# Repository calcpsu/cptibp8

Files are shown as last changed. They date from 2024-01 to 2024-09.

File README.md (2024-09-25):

# CalcPack TI BP8

A Li-Po battery replacement design for TI BP7/8/9 battery pack calculators - e.g. TI-55, TI-30, TI Programmer, etc. The original batteries had ~ 500mAh capacity (@2.4V: 1.2Wh), while a typical 9V alkaline battery substitution as ~500mAh (@9V: 4.5Wh), albeit single-use only.

Li-Po has the advantage of far reduced self-discharge in comparison to Ni-Cd, which is an advantage for an intermittently-used device. Even with similar mAh capacity, we can expect longer battery life.

Ni-CD batteries are notorious for leaking. While Lithium Ion batteries are notorious for self-immolation, a well protected Li-Po battery (particularly in a low current application like this) should be able to be made very safe.

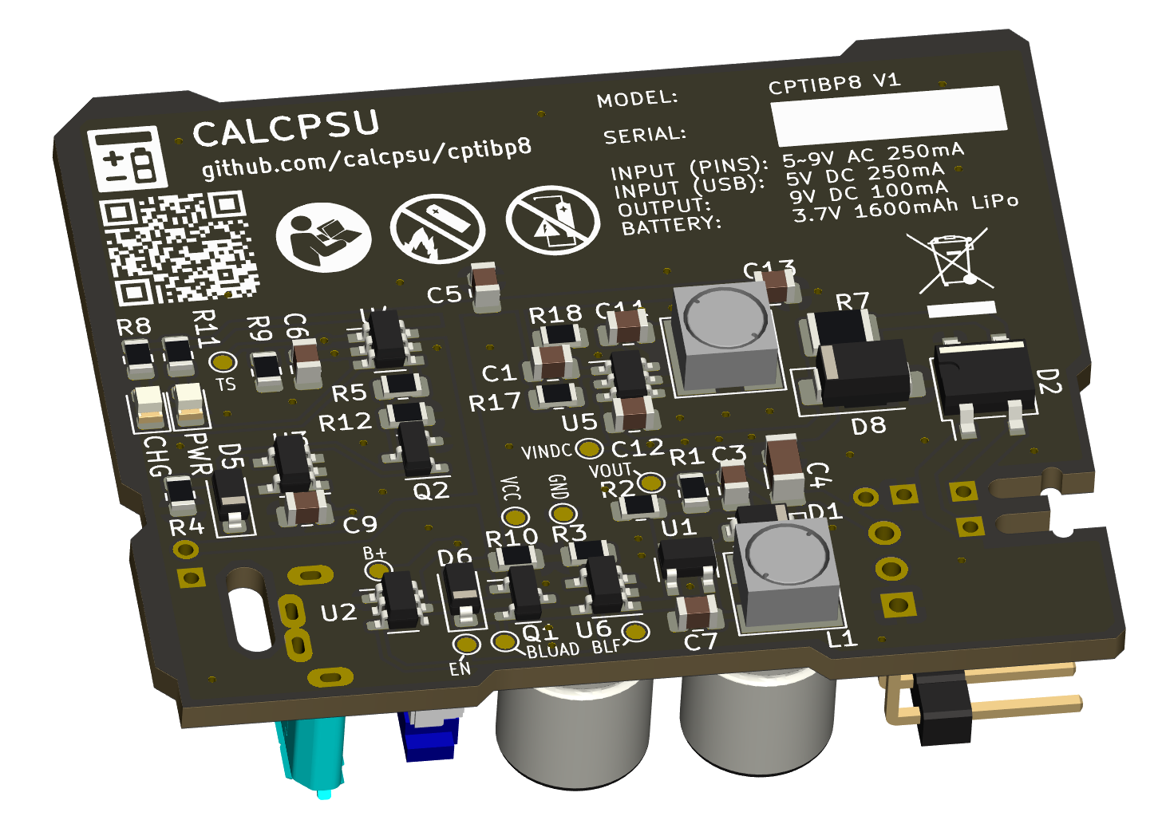
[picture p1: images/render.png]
Render of calcpack PCB


## Features / design goals:
- Direct replacement for a BP8 battery pack, compatible with TI55, TI30, TI Programmer (and other Majestic series).
    - Support both 9V battery snap terminal and 3-pin molex connector output
- Compatible with existing charging connection (2-pin AC input; somewhere from 5 to 9VAC)
    - Provides adequate smoothing of rectified AC
    - Provides voltage clamping / overvoltage protection
- Efficient conversion of input rectified supply to 5VDC for charging IC and calculator operation
- Step up from battery or input rectified supply to 9VDC for calculator supply
- Protected from:
    - Overvoltage (input) at 2x rated voltage and current (IATA requirement)
    - Overcharging (4.2V)
    - Over-discharge (3.1V shutdown, 2.5V cutoff in battery pack)
    - Short circuit and overcurrent (again for IATA requirement)
- Minimum idle/quiescent current to maximise charge time
- Similar or higher capacity than typical Ni-MH altenative (1500mAh @ 2.4V: 3.6Wh)

## Case ##

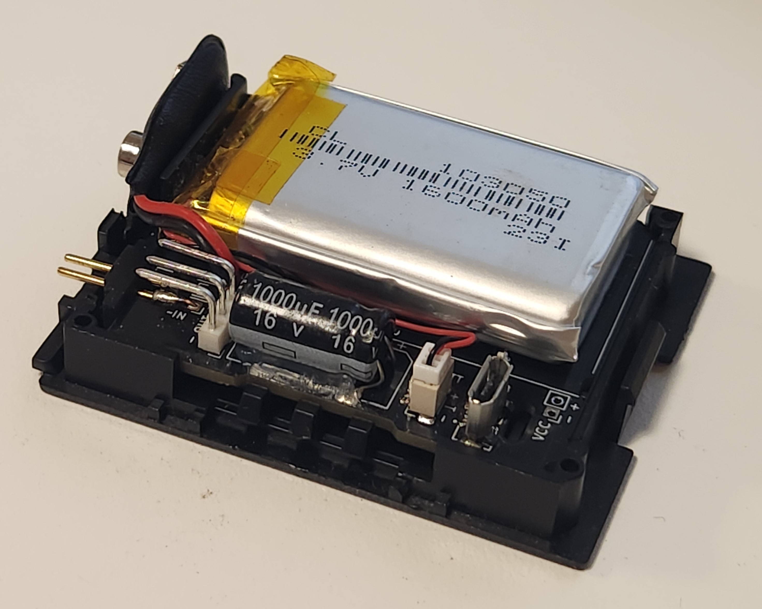
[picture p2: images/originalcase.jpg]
Photo of calcpack in original case


The board is designed to fit into the original TI case bottom part, to preserve an original look!

1. The simplest installation is to place the board and 3D printed standoff into the original case bottom, with a dab of hot glue to hold it in place.
    * The original back cover will not fit, due to ridges for cylindrical cells - you can leave it off.
    * If you prefer, a 3d-printed replacement top cover is provided compatible with the original bottom part. Due to tolerances and thin snaps, SLA 3D printing is recommended (and use a semi-flexible material, such as ABS-like resin).
3. If you don't have an original case, a case designed specifically for 3D printing is available (image below).
    * Files with and without support (intended for SLA printing) are provided.
    * The top part is not required. It is designed to be attached with a couple of dots of superglue.

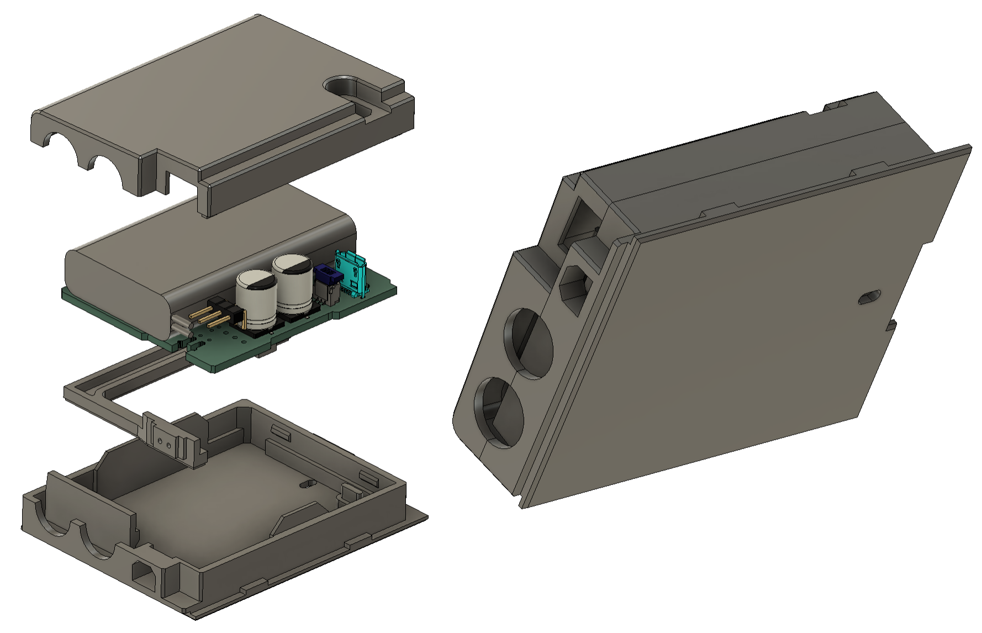
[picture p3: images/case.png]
Render of 3d printable calcpack case


## Availability ##

If you'd like one of these, I may be able to help! Please contact me at info@calcpsu.com.au.
  
## License

This work is licensed under a
[Creative Commons Attribution-NonCommercial-ShareAlike 4.0 International License][cc-by-nc-sa].

[][cc-by-nc-sa]

[cc-by-nc-sa]: http://creativecommons.org/licenses/by-nc-sa/4.0/
[cc-by-nc-sa-image]: https://licensebuttons.net/l/by-nc-sa/4.0/88x31.png
[cc-by-nc-sa-shield]: https://img.shields.io/badge/License-CC%20BY--NC--SA%204.0-lightgrey.svg

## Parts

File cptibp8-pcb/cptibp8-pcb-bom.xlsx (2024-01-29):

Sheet: cptibp8-pcb
Id | Designator | Footprint | Quantity | Designation | Supplier and ref | Column1 | _1 | MPN
6 | BT1 | JST_SH_BM03B-SRSS-TB_1x03-1MP_P1.00mm_Vertical | 1 | LiPo |  |  |  | BM03B-SRSS-TB
25 | C1 | C_0805_2012Metric | 1 | 100p |  |  |  | CC0805KRX7R8BB101
12 | C11 | C_0805_2012Metric | 1 | 22n |  |  |  | CC0805KRX7R8BB223
14 | C13,C12,C2 | C_0805_2012Metric | 3 | 1u |  |  |  | CL21B105KAFNNNE
18 | C3 | C_0805_2012Metric | 1 | 1n |  |  |  | CL21C472JAFNNNE
43 | C4 | C_1206_3216Metric | 1 | 22u |  |  |  | CL31A226KAHNNNE
41 | C5 | C_0805_2012Metric | 1 | 10u |  |  |  | CL21A106KAYNNNE
46 | C7,C6 | C_0805_2012Metric | 2 | 4u7 |  |  |  | CL21A475KAQNNNE
3 | C8,C10 | CP_Elec_8x10.5 | 2 | 470u/25V |  |  |  | EEE-FP1C471AP
34 | D1,D6 | D_SOD-123 | 2 | PMEG40T10ERX |  |  |  | PMEG40T10ERX
17 | D2 | TO-269AA | 1 | MB14S |  |  |  | MB14S
28 | D3 | LED_0805_2012Metric | 1 | RED |  |  |  | B1701USD-20D000114U1930
35 | D4 | LED_0805_2012Metric | 1 | GRN |  |  |  | B1701UYG-20D000114U1930
36 | D8 | D_SMA | 1 | Z15V |  |  |  | 3SMAJ5929B-TP
45 | F1 | Fuse_1210_3225Metric | 1 | 0ZCJ0035AF2E |  |  |  | 0ZCJ0035AF2E
1 | J1 | PinHeader_1x01_P2.00mm_Vertical | 1 | VAC2 |  |  |  | #N/A
2 | J2 | PinHeader_1x02_P2.00mm_Vertical | 1 | OUT |  |  |  | 232
7 | J3 | PinHeader_1x02_P2.00mm_Vertical | 1 | VCC |  |  |  | #N/A
4 | J4 | PinHeader_1x03_P2.54mm_Vertical | 1 | OUT |  |  |  | 22052031
5 | J5 | PinHeader_1x01_P2.00mm_Vertical | 1 | VAC1 |  |  |  | #N/A
31 | L2,L1 | Inductor_Bourns_SRR4028 | 2 | 10uH |  |  |  | SRR4028-100Y
24 | Q1 | SOT-23 | 1 | AO3413 |  |  |  | AO3413
19 | Q3 | SOT-23 | 1 | DMG2302UK |  |  |  | DMG2302U-7
23 | R1 | R_0805_2012Metric | 1 | 576k |  |  |  | RC0805FR-07576KL
10 | R10 | R_0805_2012Metric | 1 | 47k |  |  |  | RC0805FR-0747KL
11 | R11,R8 | R_0805_2012Metric | 2 | 3k |  |  |  | RC0805FR-073KL
29 | R14 | R_0805_2012Metric | 1 | 5k4 |  |  |  | RC0805FR-071K3L
16 | R17 | R_0805_2012Metric | 1 | 49.9k |  |  |  | RC0805FR-0749K9L
42 | R18 | R_0805_2012Metric | 1 | 9.1k |  |  |  | RC0805FR-079K1L
44 | R2 | R_0805_2012Metric | 1 | 91k |  |  |  | RC0805FR-0791KL
21 | R6 | R_0805_2012Metric | 1 | 1M |  |  |  | RC0805FR-7W1ML
30 | R7 | R_1210_3225Metric | 1 | 1 |  |  |  | RC1210FR-071RL
15 | R9 | R_0805_2012Metric | 1 | 10k |  |  |  | RC0805FR-0710KL
22 | TP1 | TestPoint_Pad_D1.0mm | 1 | VINDC |  |  |  | #N/A
26 | TP10 | TestPoint_Pad_D1.0mm | 1 | VOUTN |  |  |  | #N/A
13 | TP2 | TestPoint_Pad_D1.0mm | 1 | B+ |  |  |  | #N/A
33 | TP3 | TestPoint_Pad_D1.0mm | 1 | BLOAD |  |  |  | #N/A
40 | TP4 | TestPoint_Pad_D1.0mm | 1 | VOUT |  |  |  | #N/A
48 | TP5 | TestPoint_Pad_D1.0mm | 1 | VOUTF |  |  |  | #N/A
38 | TP6 | TestPoint_Pad_D1.0mm | 1 | GND |  |  |  | #N/A
47 | TP7 | TestPoint_Pad_D1.0mm | 1 | EN |  |  |  | #N/A
20 | TP8 | TestPoint_Pad_D1.0mm | 1 | TS |  |  |  | #N/A
39 | TP9 | TestPoint_Pad_D1.0mm | 1 | VCC |  |  |  | #N/A
37 | U1 | SOT-23-5_TI_DBV5 | 1 | MIC2250-1YD5-TR |  |  |  | MIC2250-1YD5-TR
9 | U2 | SOT-23-3 | 1 | APX803S-31SA |  |  |  | APX803S-31SA
32 | U4 | SOT-23-6_TI_DBV6 | 1 | BQ21040 |  |  |  | BQ21040DBVR
27 | U5 | TSOT-23-6 | 1 | AP63200WU |  |  |  | AP63200WU-7

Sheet: Sheet1
LiPo | BM03B-SRSS-TB
100p | CC0805KRX7R8BB101
22n | CC0805KRX7R8BB223
1u | CL21B105KAFNNNE
1n | CL21C472JAFNNNE
22u | CL31A226KAHNNNE
10u | CL21A106KAYNNNE
4u7 | CL21A475KAQNNNE
470u/25V | EEE-FP1C471AP
PMEG40T10ERX | PMEG40T10ERX
MB14S | MB14S
RED | B1701USD-20D000114U1930
GRN | B1701UYG-20D000114U1930
Z15V | 3SMAJ5929B-TP
0ZCJ0035AF2E | 0ZCJ0035AF2E
VAC2 | #N/A
OUT | 232
VCC | #N/A
OUT | 22052031
VAC1 | #N/A
10uH | SRR4028-100Y
AO3413 | AO3413
DMG2302UK | DMG2302U-7
576k | RC0805FR-07576KL
47k | RC0805FR-0747KL
3k | RC0805FR-073KL
5k4 | RC0805FR-071K3L
49.9k | RC0805FR-0749K9L
9.1k | RC0805FR-079K1L
91k | RC0805FR-0791KL
1M | RC0805FR-7W1ML
1 | RC1210FR-071RL
10k | RC0805FR-0710KL
VINDC | #N/A
VOUTN | #N/A
B+ | #N/A
BLOAD | #N/A
VOUT | #N/A
VOUTF | #N/A
GND | #N/A
EN | #N/A
TS | #N/A
VCC | #N/A
MIC2250-1YD5-TR | MIC2250-1YD5-TR
APX803S-31SA | APX803S-31SA
BQ21040 | BQ21040DBVR
AP63200WU | AP63200WU-7

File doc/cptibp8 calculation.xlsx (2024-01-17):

Parameter | Value | Unit
Calculator current | 60 | mA
U1 output voltage | 8.9 | V
U1 output power | 534 | mW
U1 efficiency | 85% | W/W
U1 input power | 628.2352941 | mW
VCC diode drop | 0.4 | V
VCC | 5.2 | V
BLOAD voltage | 4.8 | V
U1 input current | 130.8823529 | mA
VCC diode power | 52.35294118 | mW
Charge current | 100 | mA
U6 output power | 1200.588235 | mW
U6 efficiency | 90%
U6 input power | 1333.986928 | mW
Input voltage | 5.7 | VAC
Input current | 234.0327944 | mVAC

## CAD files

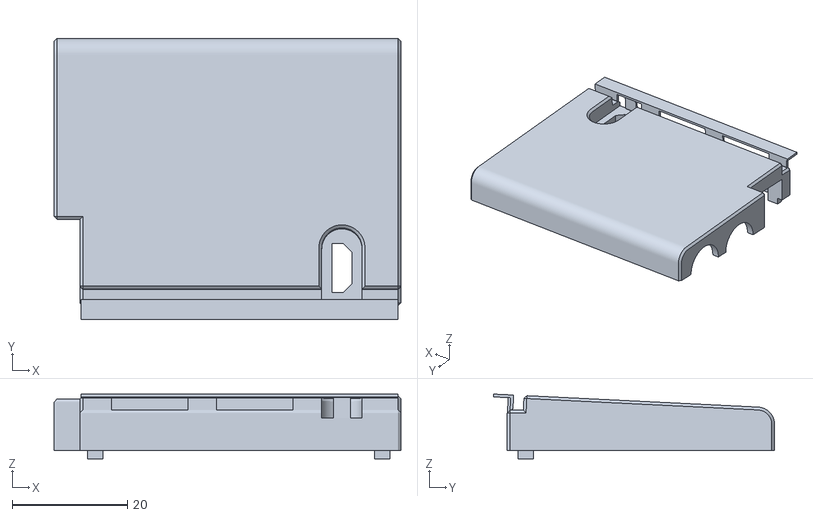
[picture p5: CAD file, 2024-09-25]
case/cptibp8_case_new_top_SLASUPPORT.stl
60.2 x 48.8 x 11.3

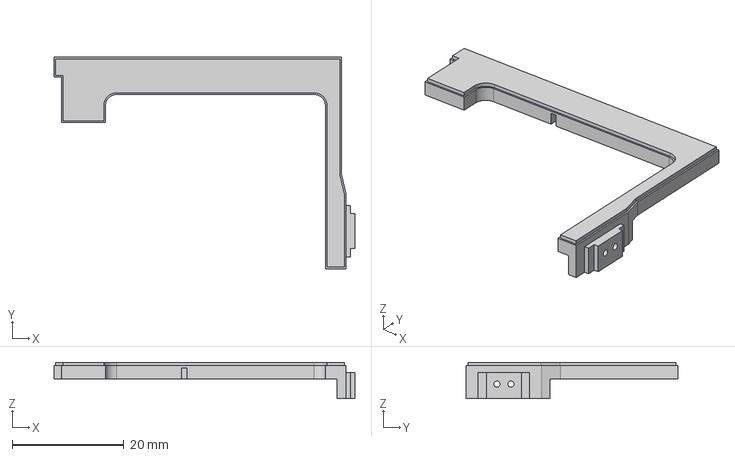
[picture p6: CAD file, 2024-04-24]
cptibp8-enclosure-spacer.step
53.8 x 37.8 x 6.50 mm

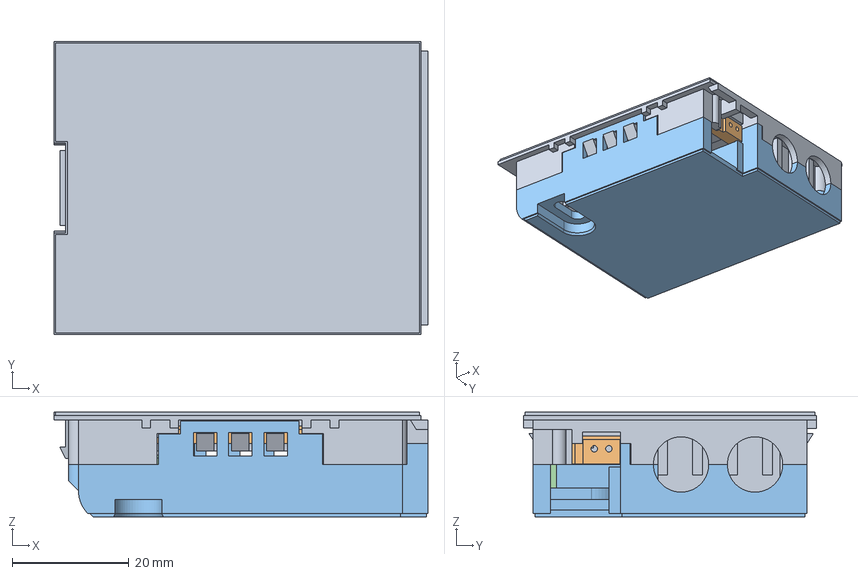
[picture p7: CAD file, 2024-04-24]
cptibp8-pcb/cptibp8-enclosure.step
64.2 x 50.3 x 18.0 mm

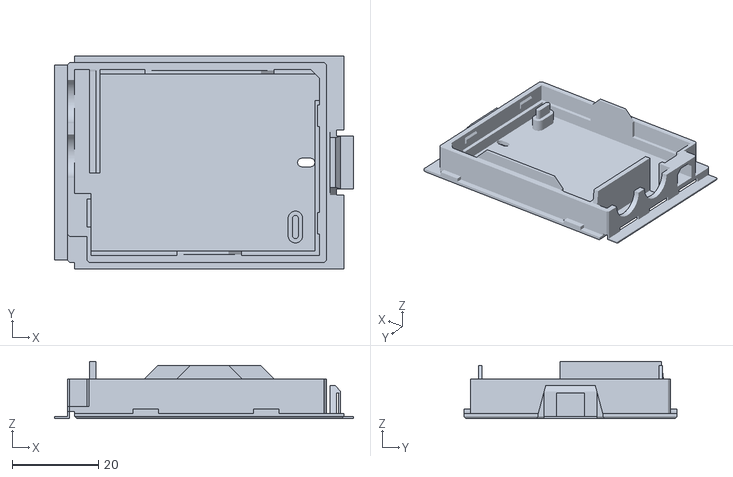
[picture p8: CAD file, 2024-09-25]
case/cptibp8_case_new_bottom_SLASUPPORT.stl
69.5 x 49.6 x 13.3

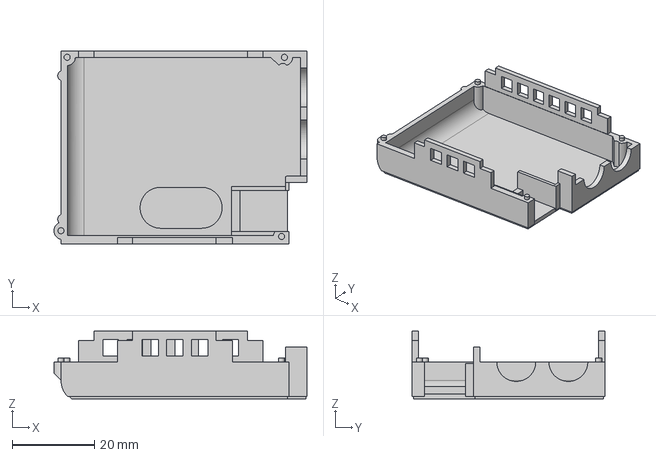
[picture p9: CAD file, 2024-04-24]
cptibp8-enclosure-lid.step
61.7 x 47.0 x 16.5 mm

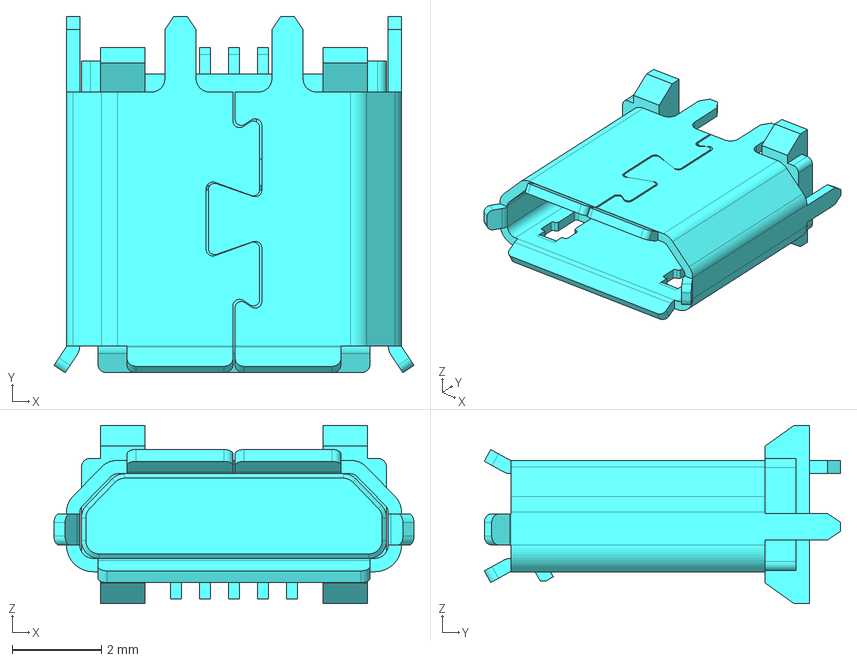
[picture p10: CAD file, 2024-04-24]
cptibp8-pcb/3d/ZX80-B-5P_30__1.step
8.08 x 8.00 x 4.00 mm

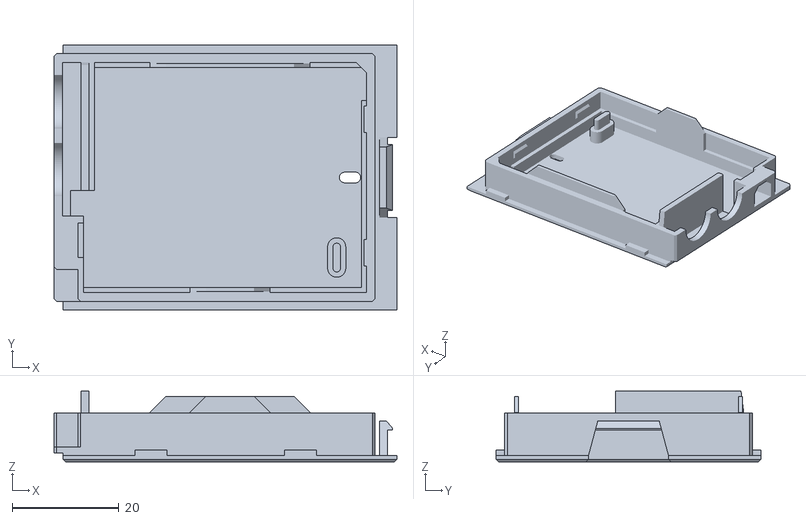
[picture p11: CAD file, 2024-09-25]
case/cptibp8_case_new_bottom.stl
64.3 x 49.6 x 13.3

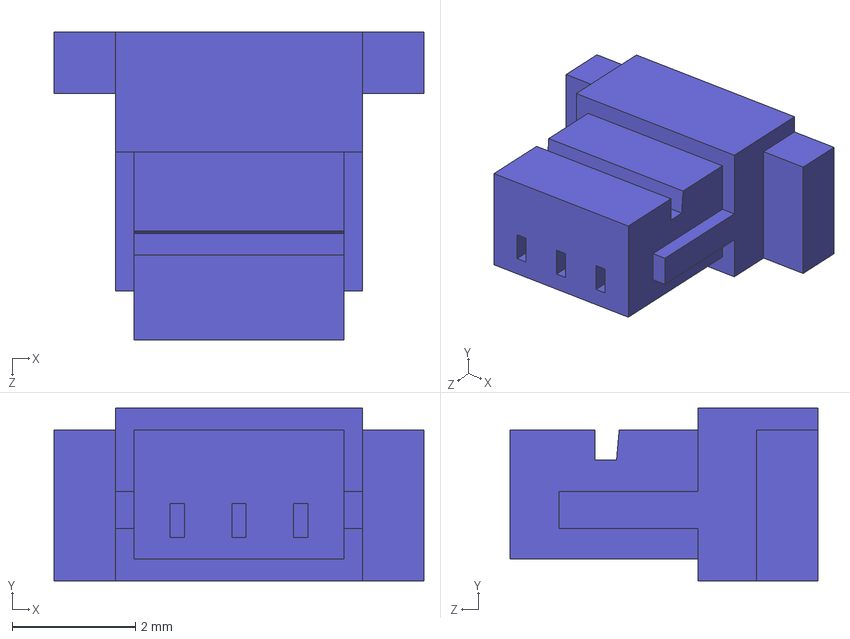
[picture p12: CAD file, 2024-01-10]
cptibp8-pcb/3d/SHR-03V-S-B.STEP
6.00 x 2.80 x 5.00 mm

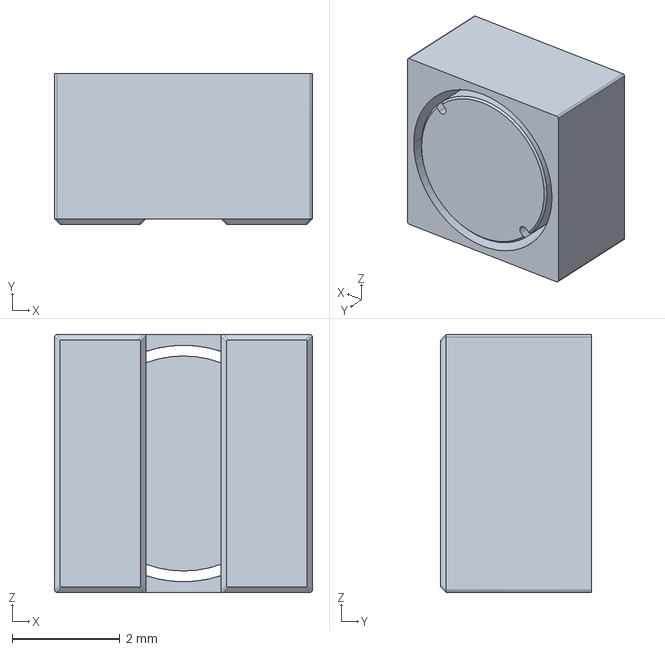
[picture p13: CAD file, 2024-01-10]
cptibp8-pcb/3d/srr4028.stp
4.80 x 2.80 x 4.80 mm

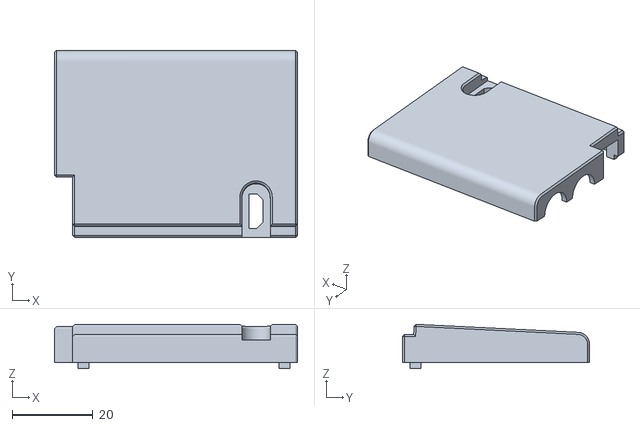
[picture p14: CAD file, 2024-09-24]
case/cptibp8_case_new_top.stl
60.2 x 46.4 x 11.0

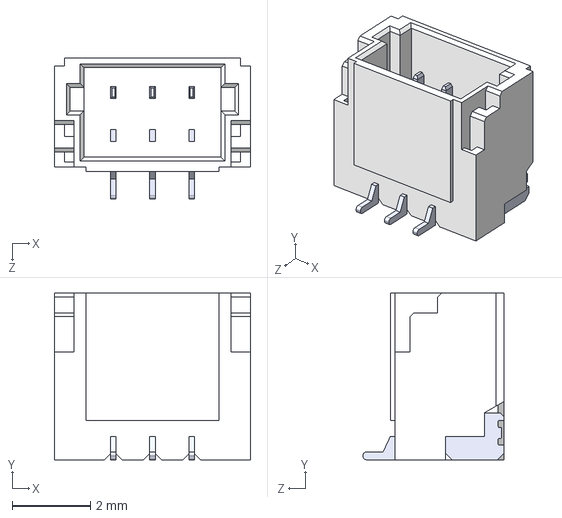
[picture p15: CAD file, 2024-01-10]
cptibp8-pcb/3d/BM03B-SRSS-TB.STEP
5.00 x 4.25 x 3.60 mm

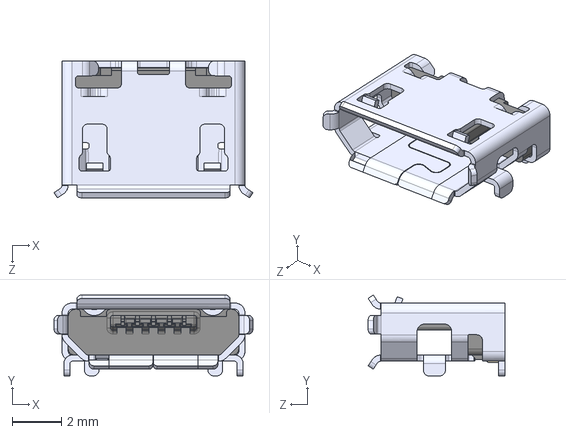
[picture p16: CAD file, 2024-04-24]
cptibp8-pcb/3d/10118194-0001LF.step
8.05 x 3.27 x 5.53 mm

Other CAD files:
case/cptibp8_case_original_top.stl
case/cptibp8_case_new_standoff.stl

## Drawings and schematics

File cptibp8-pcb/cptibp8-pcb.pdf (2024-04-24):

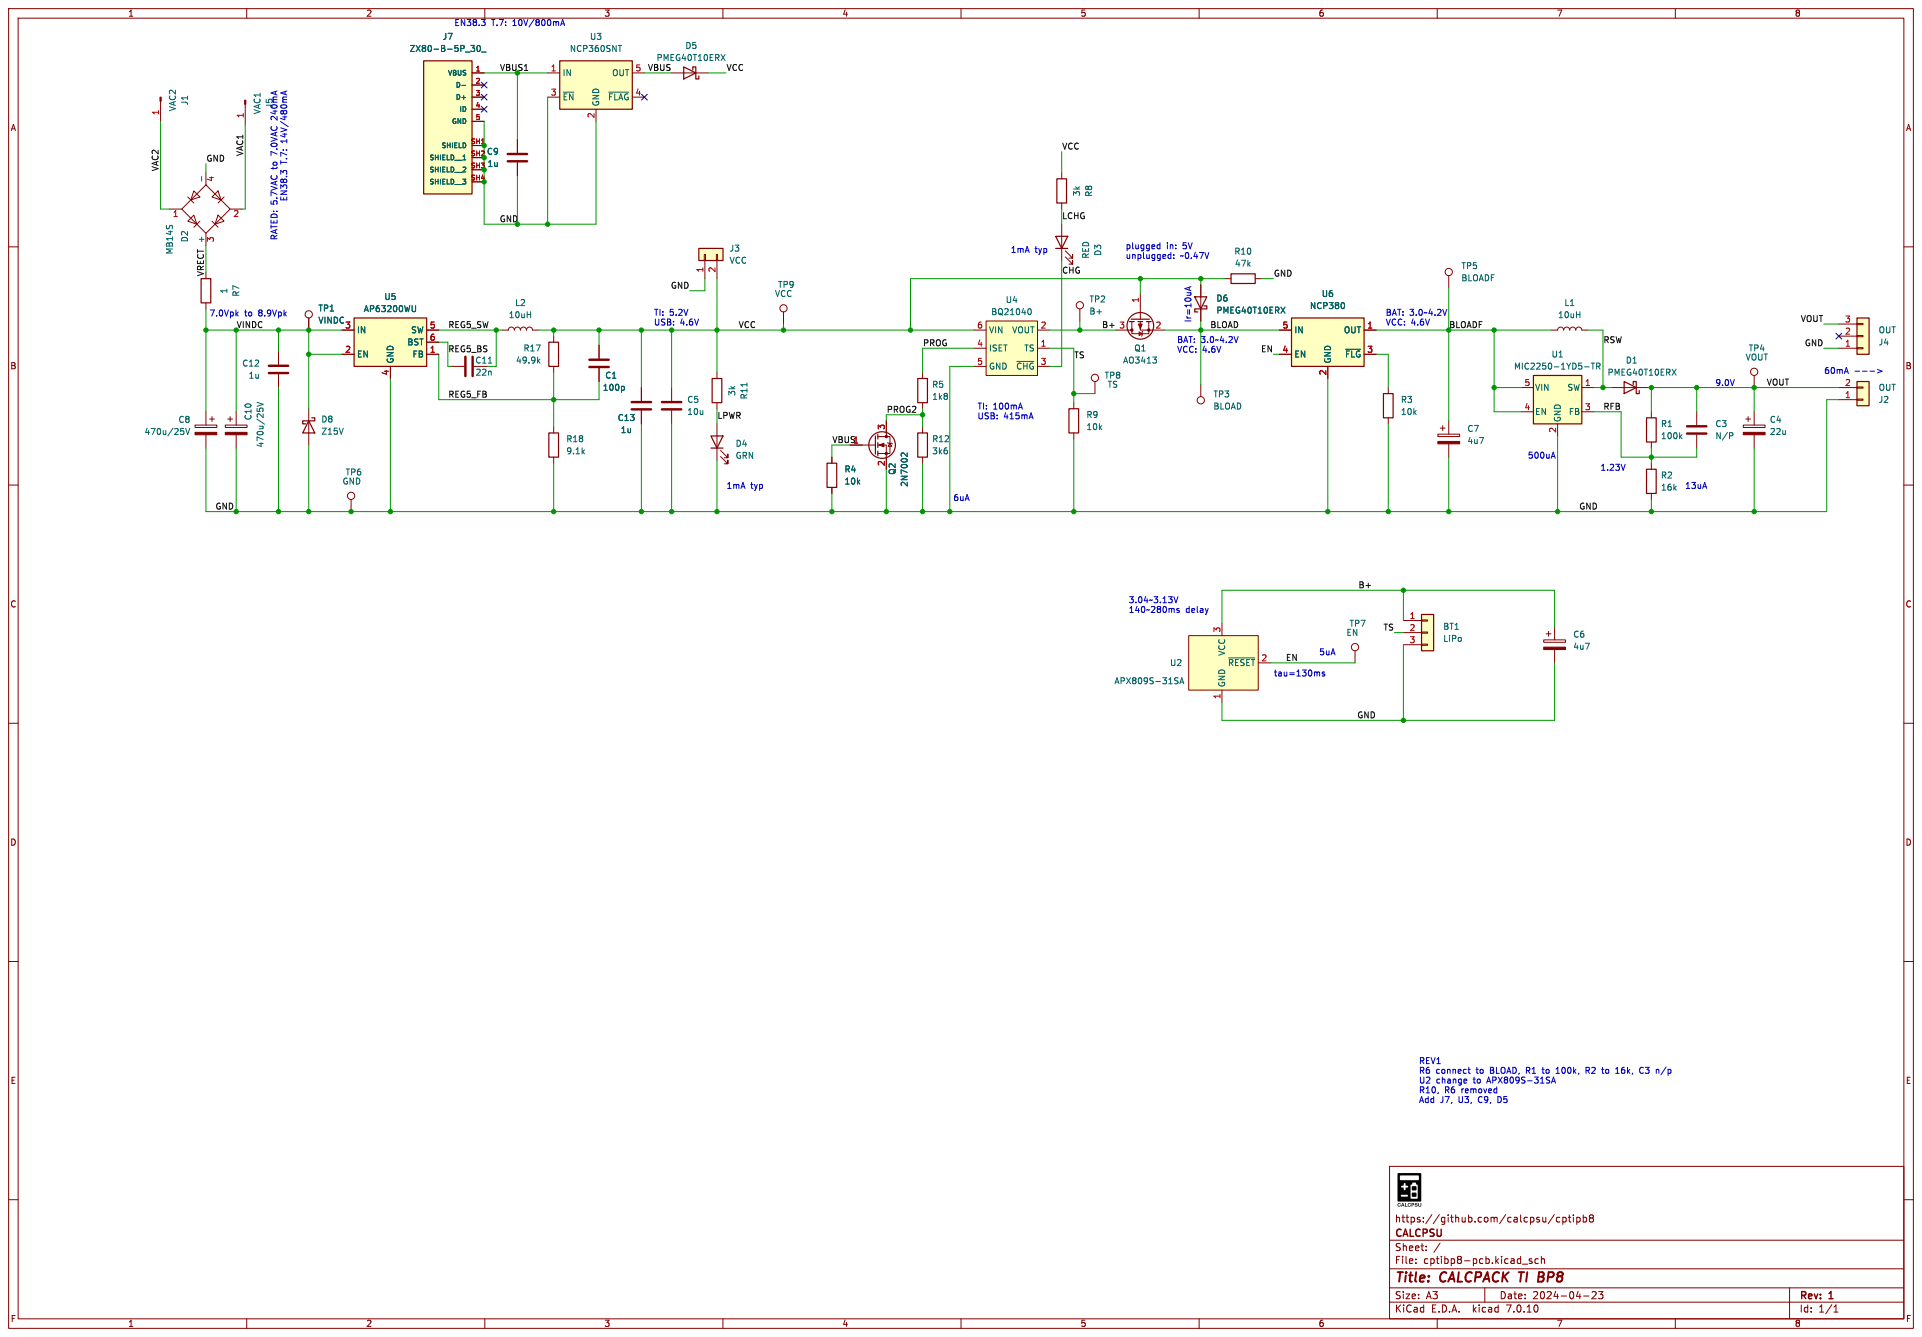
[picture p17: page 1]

2 FB 3 EN 4 VIN 5 U1 MIC2250-1YD5-TR

REV1 R6 connect to BLOAD, R1 to 100k, R2 to 16k, C3 n/p U2 change to APX809S-31SA R10, R6 removed Add J7, U3, C9, D5

https://github.com/calcpsu/cptipb8
File: cptibp8-pcb.kicad_sch Sheet: / CALCPSU

Id: 1/1 Title: CALCPACK TI BP8

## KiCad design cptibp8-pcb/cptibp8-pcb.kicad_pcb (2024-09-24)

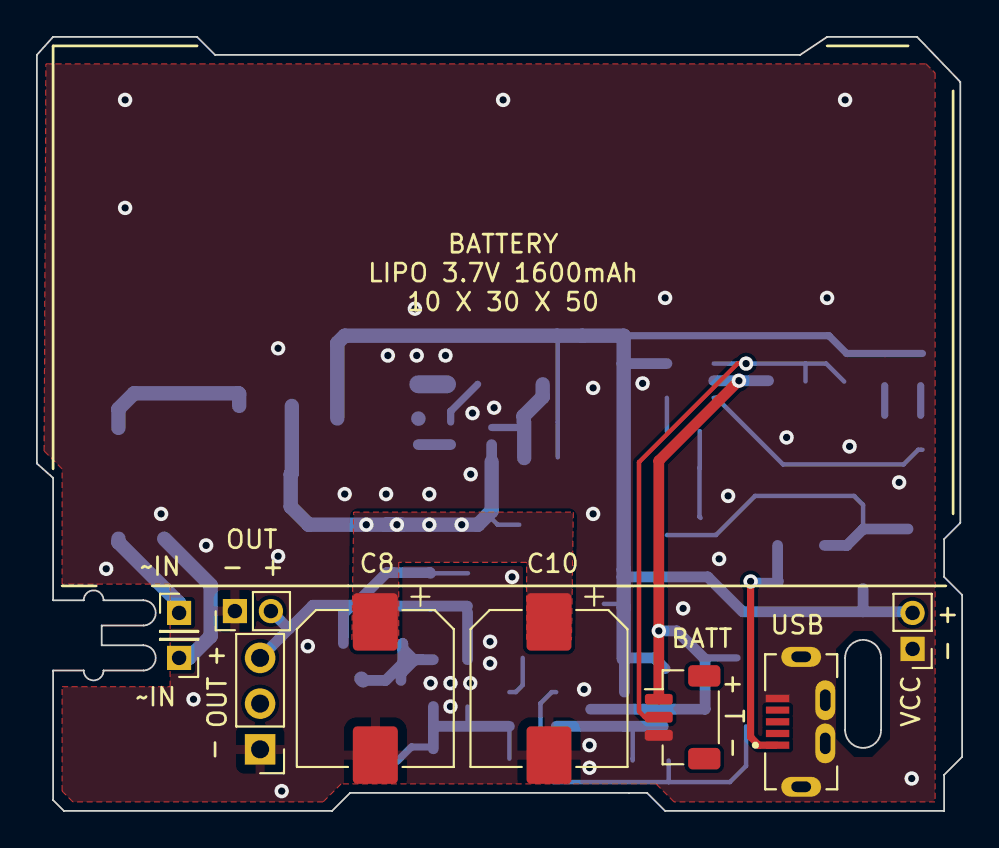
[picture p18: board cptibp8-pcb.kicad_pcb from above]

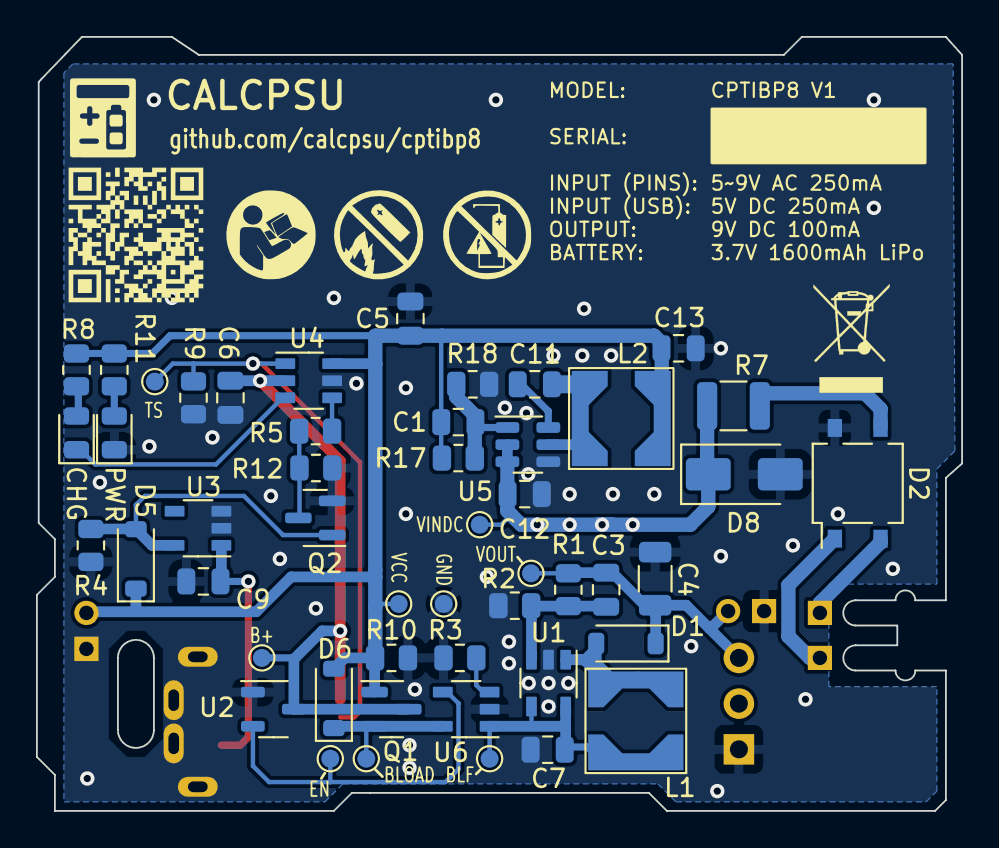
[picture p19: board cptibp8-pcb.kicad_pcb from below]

Board: 2 copper layers, 51.4 x 43.0 mm, 58 parts (49 on the bottom side), 25 nets.

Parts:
BT1: LiPo; JST_SH_BM03B-SRSS-TB_1x03-1MP_P1.00mm_Vertical
C1: 100p; C_0805_2012Metric
C3: N/P; C_0805_2012Metric
C4: 22u; C_1206_3216Metric
C5: 10u; C_0805_2012Metric
C6, C7: 4u7; C_0805_2012Metric
C8, C10: 470u/25V; CP_Elec_8x10.5
C9, C12, C13: 1u; C_0805_2012Metric
C11: 22n; C_0805_2012Metric
D1, D5, D6: PMEG40T10ERX; D_SOD-123
D2: MB14S; TO-269AA
D3: RED; LED_0805_2012Metric
D4: GRN; LED_0805_2012Metric
D8: Z15V; D_SMA
J1: VAC2; PinHeader_1x01_P2.00mm_Vertical
J2: OUT; PinHeader_1x02_P2.00mm_Vertical
J3: VCC; PinHeader_1x02_P2.00mm_Vertical
J4: OUT; PinHeader_1x03_P2.54mm_Vertical
J5: VAC1; PinHeader_1x01_P2.00mm_Vertical
J7: ZX80-B-5P_30_; HRS_ZX80-B-5P_30_
L1, L2: 10uH; Inductor_Bourns_SRR4028
Q1: AO3413; SOT-23
Q2: 2N7002; SOT-23
R1: 100k; R_0805_2012Metric
R2: 16k; R_0805_2012Metric
R3, R4, R9: 10k; R_0805_2012Metric
R5: 1k8; R_0805_2012Metric
R7: 1; R_1210_3225Metric
R8, R11: 3k; R_0805_2012Metric
R10: 47k; R_0805_2012Metric
R12: 3k6; R_0805_2012Metric
R17: 49.9k; R_0805_2012Metric
R18: 9.1k; R_0805_2012Metric
TP1: VINDC; TestPoint_Pad_D1.0mm
TP2: B+; TestPoint_Pad_D1.0mm
TP3: BLOAD; TestPoint_Pad_D1.0mm
TP4: VOUT; TestPoint_Pad_D1.0mm
TP5: BLOADF; TestPoint_Pad_D1.0mm
TP6: GND; TestPoint_Pad_D1.0mm
TP7: EN; TestPoint_Pad_D1.0mm
TP8: TS; TestPoint_Pad_D1.0mm
TP9: VCC; TestPoint_Pad_D1.0mm
U1: MIC2250-1YD5-TR; SOT-23-5_TI_DBV5
U2: APX809S-31SA; SOT-23-3
U3: NCP360SNT; SOT-23-5_TI_DBV5
U4: BQ21040; SOT-23-6_TI_DBV6
U5: AP63200WU; TSOT-23-6
U6: NCP380; SOT-23-5_TI_DBV5

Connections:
/B+: BT1.1, C6.1, Q1.3 (D), TP2.1, U2.3 (VCC), U4.2 (VOUT)
/BLOAD: D6.1 (K), Q1.2 (S), TP3.1, U6.5 (IN)
/BLOADF: C7.1, L1.1, TP5.1, U1.4 (EN), U1.5 (VIN), U6.1 (OUT)
/CHG: D3.1 (K), U4.3 (~CHG)
/EN: TP7.1, U2.2 (~RESET), U6.4 (EN)
/GND: BT1.3, C4.2, C5.2, C6.2, C7.2, C8.2, C9.2, C10.2, C12.2, C13.2, D2.4 (-), D4.1 (K), D8.2 (A), J2.1, J3.1, J4.1, J7.5 (GND), J7.SH1 (SHIELD), J7.SH2 (SHIELD__1), J7.SH3 (SHIELD__2), J7.SH4 (SHIELD__3), Q2.2 (S), R2.1, R3.1, R4.1, R9.1, R10.1, R12.1, R18.2, TP6.1, U1.2 (GND), U2.1 (GND), U3.2 (GND), U3.3 (~EN), U4.5 (GND), U5.4 (GND), U6.2 (GND)
/LCHG: D3.2 (A), R8.1
/LPWR: D4.2 (A), R11.1
/PROG: R5.2, U4.4 (ISET)
/PROG2: Q2.3 (D), R5.1, R12.2
/REG5_BS: C11.1, U5.6 (BST)
/REG5_FB: C1.1, R17.2, R18.1, U5.1 (FB)
/REG5_SW: C11.2, L2.1, U5.5 (SW)
/RFB: C3.1, R1.2, R2.2, U1.3 (FB)
/RSW: D1.2 (A), L1.2, U1.1 (SW)
/TS: BT1.2, R9.2, TP8.1, U4.1 (TS)
/VAC1: D2.2, J5.1
/VAC2: D2.1, J1.1
/VBUS: D5.2 (A), Q2.1 (G), R4.2, U3.5 (OUT)
/VBUS1: C9.1, J7.1 (VBUS), U3.1 (IN)
/VCC: C1.2, C5.1, C13.1, D5.1 (K), D6.2 (A), J3.2, L2.2, Q1.1 (G), R8.2, R10.2, R11.2, R17.1, TP9.1, U4.6 (VIN)
/VINDC: C8.1, C10.1, C12.1, D8.1 (K), R7.2, TP1.1, U5.2 (EN), U5.3 (IN)
/VOUT: C3.2, C4.1, D1.1 (K), J2.2, J4.3, R1.1, TP4.1
/VRECT: D2.3 (+), R7.1
unnamed: R3.2, U6.3 (~FLG)

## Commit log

2024-01-10 initial commit for pcb
    [BM03B-SRSS-TB.STEP, CDRN74.stp, SHR-03V-S-B.STEP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]
2024-01-17 Fix typo. Update design.
    [BM03B-SRSS-TB.STEP, CDRN74.stp, SHR-03V-S-B.STEP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]
2024-01-18 update and plot v0.1
    [cptibp8-pcb-B_Cu.gbr, cptibp8-pcb-B_Mask.gbr, cptibp8-pcb-B_Paste.gbr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]
2024-01-29 rev0 final
    [cptibp8-pcb-B_Cu.gbr, cptibp8-pcb-B_Mask.gbr, cptibp8-pcb-B_Paste.gbr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]
2024-03-06 update enclosure and project
    [cptibp8-enclosure.step, cptibp8-pcb.kicad_pcb, cptibp8-pcb.kicad_sch]
2024-09-24 Update kicad file version (8.0)
    [cptibp8-pcb.kicad_pcb, cptibp8-pcb.kicad_sch]
2024-09-24 Add case
    [cptibp8_case_new_bottom.stl, cptibp8_case_new_bottom_SLASUPPORT.stl, cptibp8_case_new_standoff.stl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]
2024-09-25 Minor tweaks to case design
    [cptibp8_case_new_bottom.stl, cptibp8_case_new_bottom_SLASUPPORT.stl, cptibp8_case_new_top_SLASUPPORT.stl]
